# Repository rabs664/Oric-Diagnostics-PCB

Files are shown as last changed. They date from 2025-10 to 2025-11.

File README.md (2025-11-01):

# Oric Diagnostics PCB
This is a reproduction of Mike Brown's Oric Diagnostic board and loopback harnesses, see [Mike Brown's Diagnostic ROM and PCB](https://oric.signal11.org.uk/html/diagrom.htm)

>[!NOTE]
>Acknowledgements go to Mike Brown for posting the original design to his excellent website [Oric And Atmos Support](https://oric.signal11.org.uk/index.htm). Many Thanks.



>[!CAUTION]
>USE AT YOUR OWN RISK.
>There is always the risk that the Oric Diagnostic board could cause harm to your Oric. Although I have tested the Oric Diagnostic board, there is no guarantee that it
>will work properly under all circumstances.

# Repository Content
This repository contains the KiCad and gerber files associated with the Diagnostic board and loopback harnesses.

# Changes from Mike Brown's Original Design
The following changes have been made from Mike Brown's Original Design:

* The clock circuit has been replaced by an [ECS-100AX-010](https://www.digikey.co.uk/en/products/detail/ecs-inc/ECS-100AX-010/827230) oscillator.

* The LED resistors have been replaced with 220ohm values.
>[!TIP]
>I still found the LEDs quite bright and you may consider increasing this value.

* LS components replaced with HCT.

* 3M holes have been added to allow for standoffs to be fitted.

For all other information about Mike Brown's original design please refer to [Mike Brown's website](https://oric.signal11.org.uk/html/diagrom.htm)

# Ribbon Cable
The Oric Diagnostic board has been designed to be used with a 34-way ribbon cable and can be used partly when the Oric motherboard is still in the case, altough it is a bit difficult to use the NMI button underneath.



However for the most part it will probably be used when the Oric motherboard has been removed from the case, but remember the motherboard is normally upside down and hence the twist in the ribbon cable when used in this configuration.



>[!TIP]
>Note the orientation of the ribbon connectors and red cable aligned to pin 1 and check connectivity back to the Oric motherboard before use.



# Port A Loopback
The Port A loopback is designed to fit straight into the Oric printer port.



>[!TIP]
>I found it difficult to remove the Port A Loopback when required. In the end I placed a pin header on the wrong side of the PCB and connected using a ribbon cable.
>
> 

# Keyboard Loopback
The Keyboard loopback is designed to fit over the end 10 pins.



>[!NOTE]
>I struggled to find pin headers that fitted. In the end I used these [pin headers](https://www.digikey.co.uk/en/products/detail/samtec-inc/SSA-110-S-T/1105806) but they are not a perfect fit.

# Casette Loopback
The Casette loopback is not part of this repository please refer to [Mike Brown's Diagnostic ROM and PCB page](https://oric.signal11.org.uk/html/diagrom.htm)

# 1MHz Clock
>[!NOTE]
>I have not had a need to use the clock source yet.



# ROM
Please refer to [Mike Brown's Diagnostic ROM and PCB page](https://oric.signal11.org.uk/html/diagrom.htm)

>[!NOTE]
>I used a 27C512 EPROM and copied the 16K ROM image four times to fill the 64K EPROM.

# Jumpers
Please refer to [Mike Brown's Diagnostic ROM and PCB page](https://oric.signal11.org.uk/html/diagrom.htm)

>[!CAUTION]
>I have not tested the jumpers A14=0, A15=0, INHIBIT VIA and VIA SEL

# Testing
The Oric Diagnostic board has been tested on two Oric-1 computers. One Oric-1 passed all tests and the other failed on the Casette Input test (which was resolved by replacing the LM358 OpAmp). So unfortunately I have not yet had to use the Oric Diagnostic board extensively on a fully failed computer.



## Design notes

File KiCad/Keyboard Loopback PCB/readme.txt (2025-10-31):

This folder contains the KiCad Project and gerbers for the Keyboard Loopback PCB.

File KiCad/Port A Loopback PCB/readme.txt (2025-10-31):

This folder contains the KiCad Project and gerbers for the Port A Loopback PCB.

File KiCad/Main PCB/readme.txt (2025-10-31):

This folder contains the KiCad Project and gerbers for the main Oric Diganostic PCB.

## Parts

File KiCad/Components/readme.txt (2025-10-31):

This folder contains the footprints for some components used in the KiCad project.

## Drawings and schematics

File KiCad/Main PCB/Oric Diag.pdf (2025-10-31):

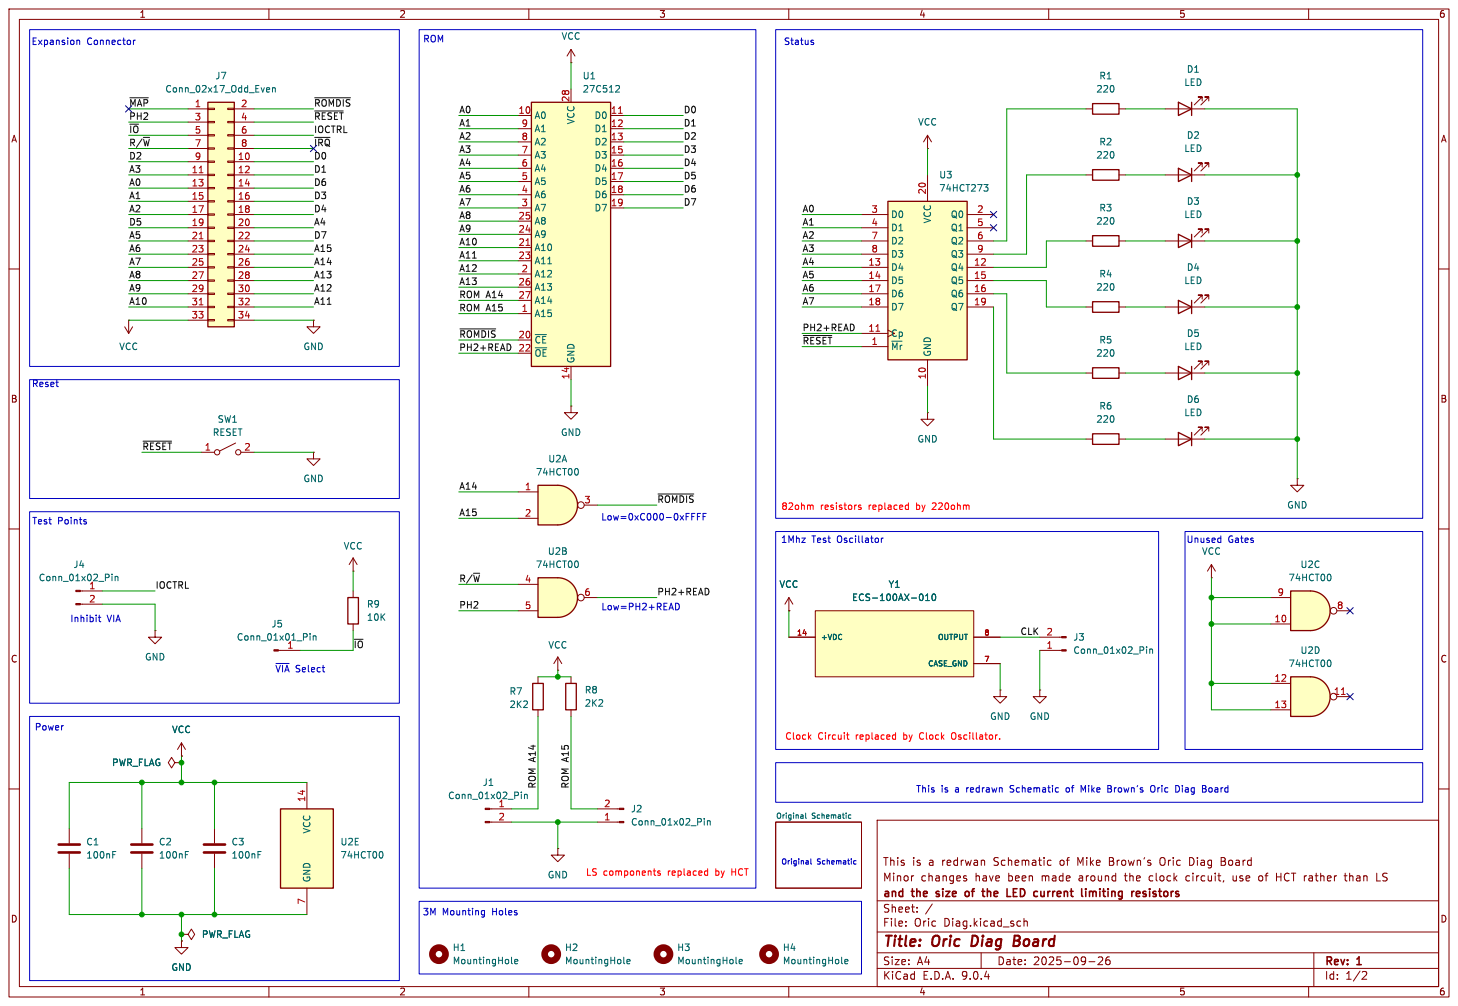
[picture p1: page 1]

Id: 1/2 Title: Oric Diag Board

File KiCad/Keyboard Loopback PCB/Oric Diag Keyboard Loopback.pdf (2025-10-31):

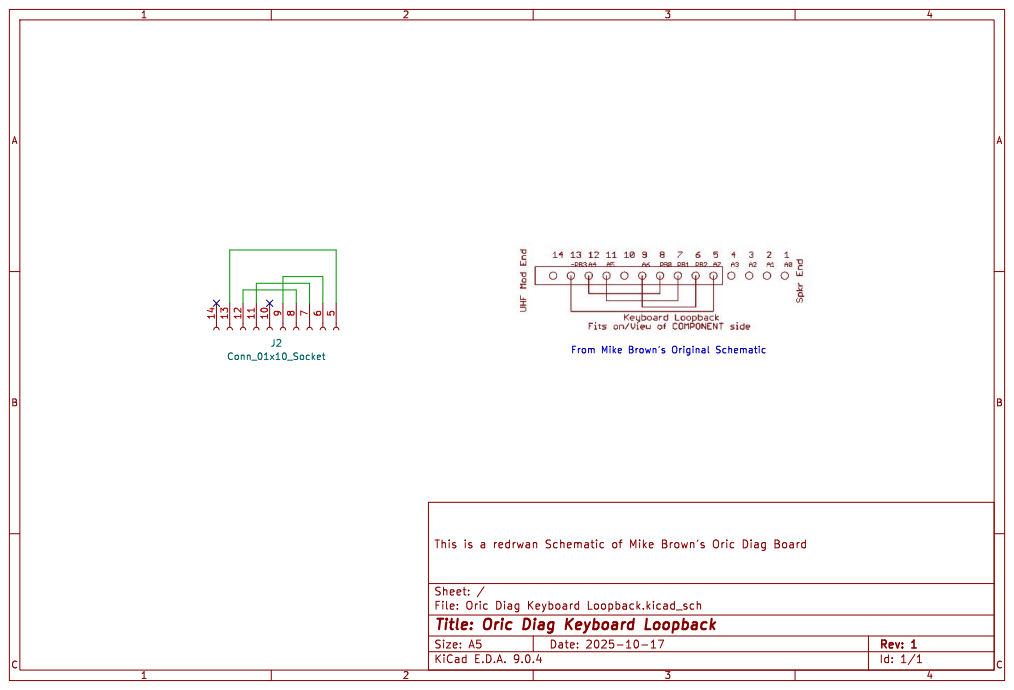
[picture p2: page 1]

51413121110 J2 Conn_01x10_Socket From Mike Brown's Original Schematic

Id: 1/1 Title: Oric Diag Keyboard Loopback

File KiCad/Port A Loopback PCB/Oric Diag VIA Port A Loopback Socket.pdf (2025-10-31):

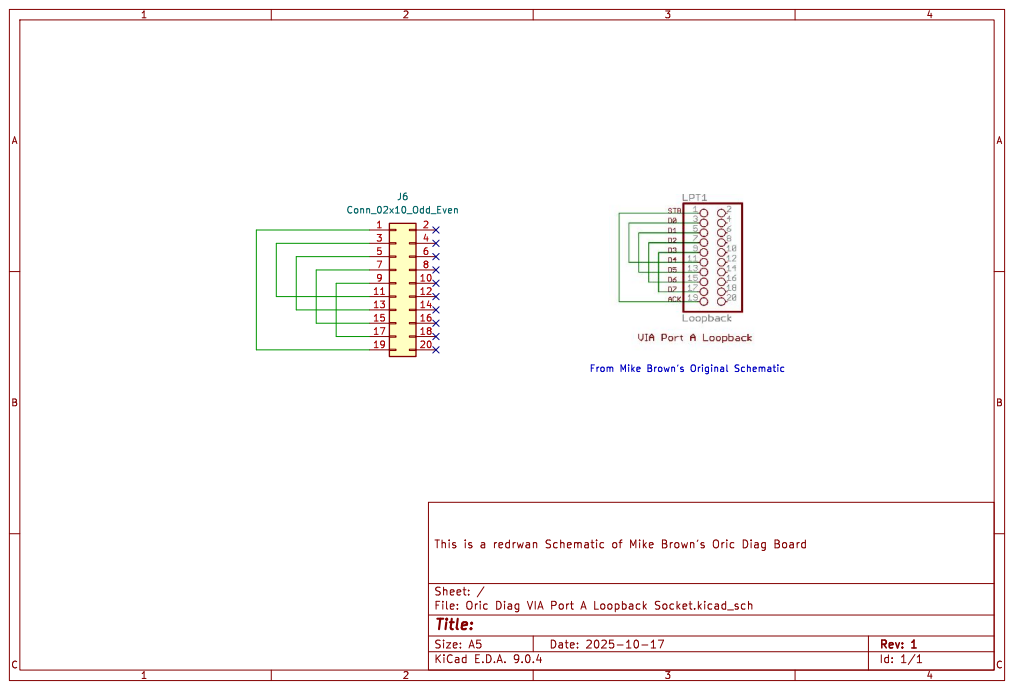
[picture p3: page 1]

9 | 10
11 | 12
13 | 14
15 | 16
17 | 18

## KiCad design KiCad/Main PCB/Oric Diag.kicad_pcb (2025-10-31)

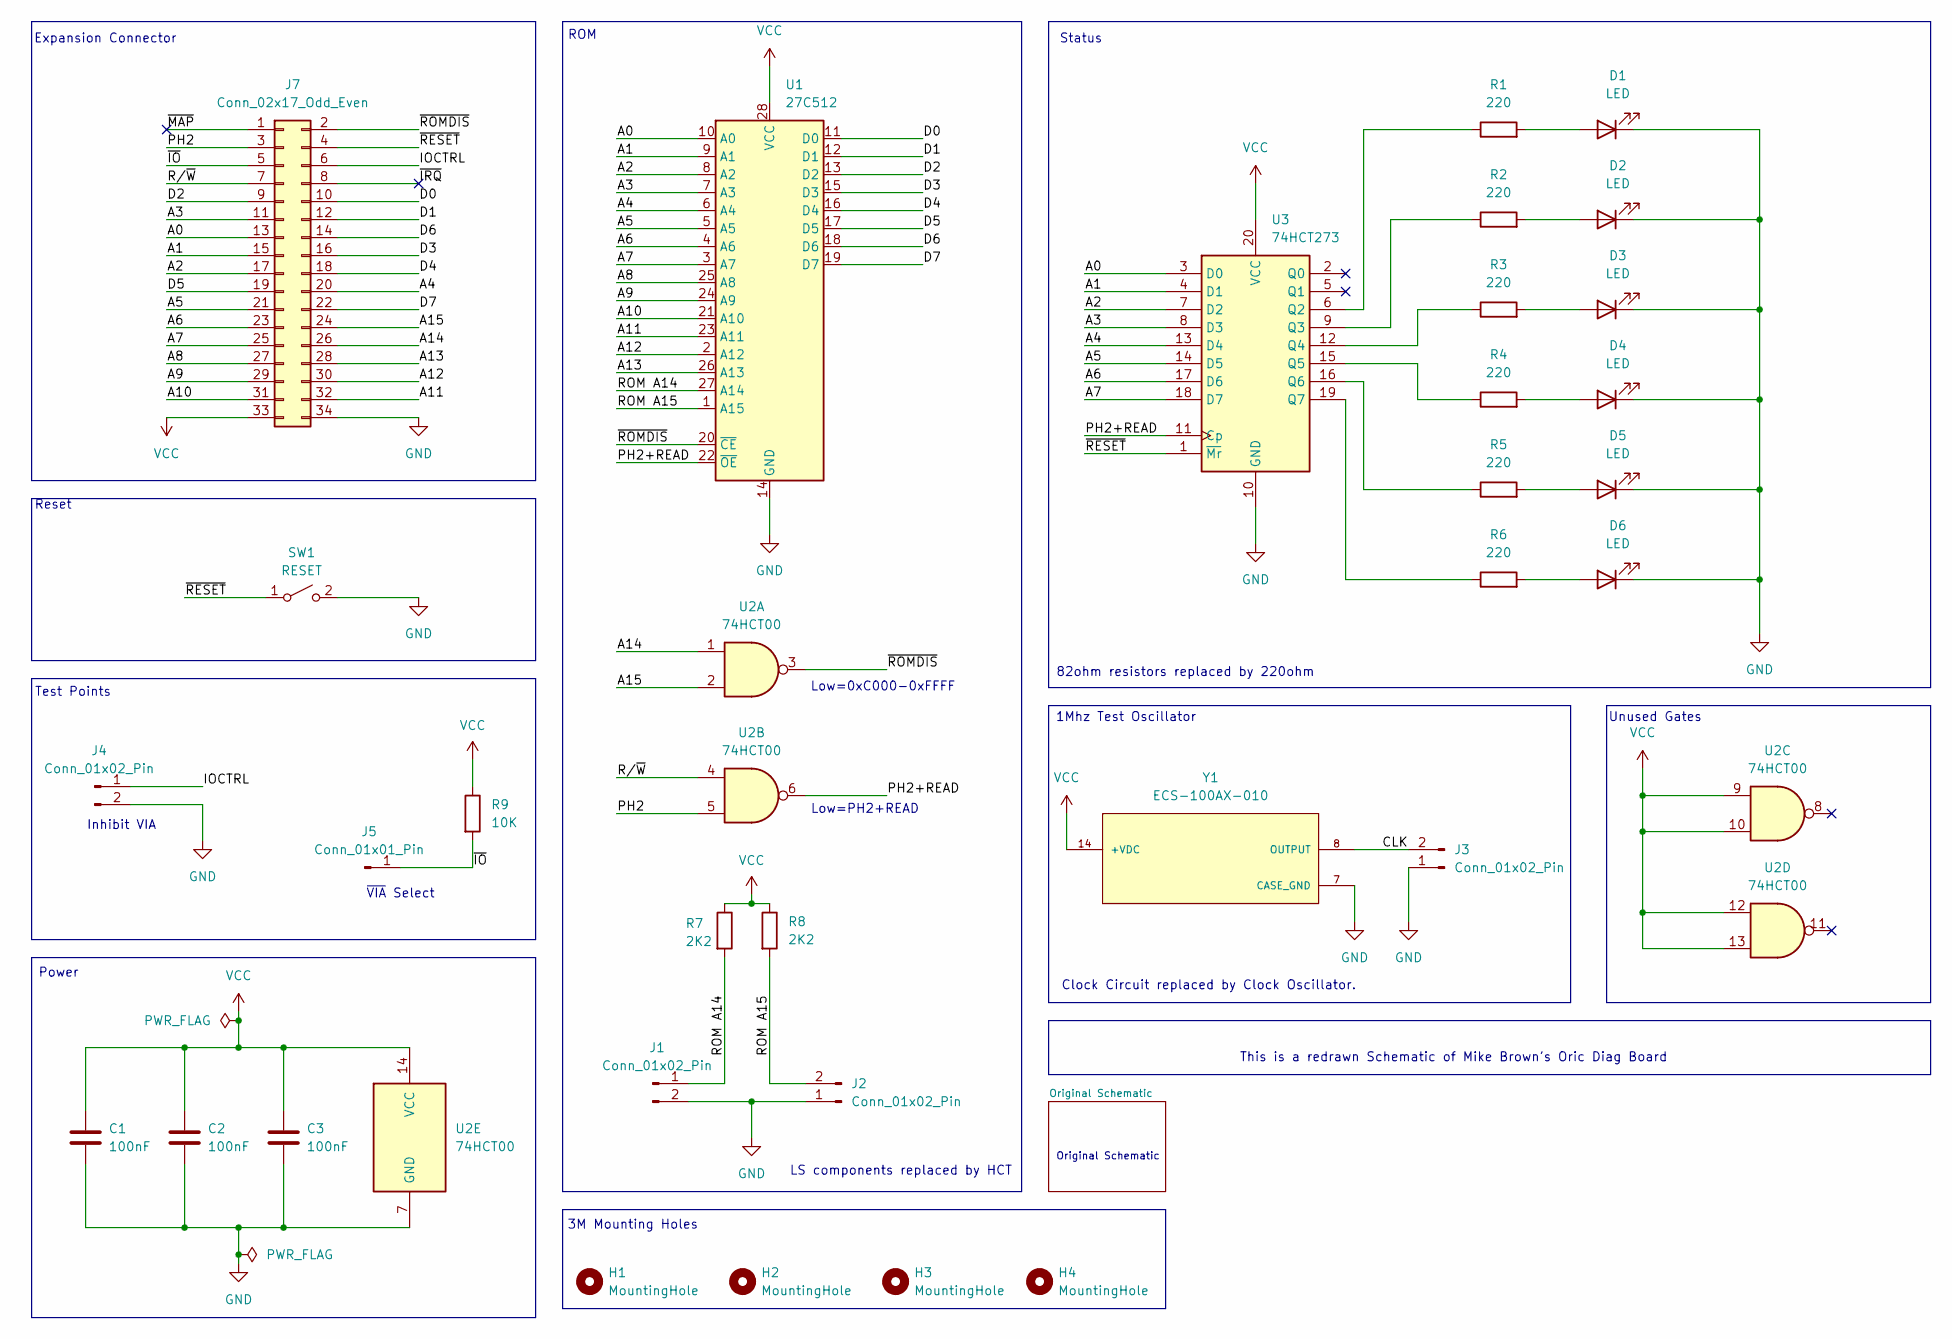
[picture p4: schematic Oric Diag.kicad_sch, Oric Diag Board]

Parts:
C1, C2, C3: 100nF; C_Disc_D5.0mm_W2.5mm_P5.00mm
D1, D2, D3, D4, D5, D6: LED; LED_D3.0mm
H1, H2, H3, H4: MountingHole; MountingHole_3.2mm_M3
J1, J2, J3, J4: Conn_01x02_Pin; PinHeader_1x02_P2.54mm_Vertical
J5: Conn_01x01_Pin; PinHeader_1x01_P2.00mm_Vertical
J7: Conn_02x17_Odd_Even; IDC-Header_2x17_P2.54mm_Vertical
R1, R2, R3, R4, R5, R6: 220; R_Axial_DIN0207_L6.3mm_D2.5mm_P7.62mm_Horizontal
R7, R8: 2K2; R_Axial_DIN0207_L6.3mm_D2.5mm_P7.62mm_Horizontal
R9: 10K; R_Axial_DIN0207_L6.3mm_D2.5mm_P7.62mm_Horizontal
SW1: RESET; SW_PUSH_6mm_H9.5mm
U1: 27C512; DIP-28_W15.24mm
U2: 74HCT00; DIP-14_W7.62mm_Socket
U3: 74HCT273; DIP-20_W7.62mm
Y1: ECS-100AX-010; OSC_ECS-100AX-010

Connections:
/A0: J7.13, U1.10 (A0), U3.3 (D0)
/A1: J7.15, U1.9 (A1), U3.4 (D1)
/A2: J7.17, U1.8 (A2), U3.7 (D2)
/A3: J7.11, U1.7 (A3), U3.8 (D3)
/A4: J7.20, U1.6 (A4), U3.13 (D4)
/A5: J7.21, U1.5 (A5), U3.14 (D5)
/A6: J7.23, U1.4 (A6), U3.17 (D6)
/A7: J7.25, U1.3 (A7), U3.18 (D7)
/A8: J7.27, U1.25 (A8)
/A9: J7.29, U1.24 (A9)
/A10: J7.31, U1.21 (A10)
/A11: J7.32, U1.23 (A11)
/A12: J7.30, U1.2 (A12)
/A13: J7.28, U1.26 (A13)
/A14: J7.26, U2.1
/A15: J7.24, U2.2
/CLK: J3.2, Y1.8 (OUTPUT)
/D0: J7.10, U1.11 (D0)
/D1: J7.12, U1.12 (D1)
/D2: J7.9, U1.13 (D2)
/D3: J7.16, U1.15 (D3)
/D4: J7.18, U1.16 (D4)
/D5: J7.19, U1.17 (D5)
/D6: J7.14, U1.18 (D6)
/D7: J7.22, U1.19 (D7)
/IOCTRL: J4.1, J7.6
/PH2: J7.3, U2.5
/PH2+READ: U1.22 (~OE), U2.6, U3.11 (Cp)
/ROM A14: J1.1, R7.2, U1.27 (A14)
/ROM A15: J2.2, R8.2, U1.1 (A15)
/R/~W: J7.7, U2.4
/~IO: J5.1, J7.5, R9.2
/~IRQ: J7.8
/~MAP: J7.1
/~RESET: J7.4, SW1.1 (A), U3.1 (~Mr)
/~ROMDIS: J7.2, U1.20 (~CE), U2.3
GND: C1.2, C2.2, C3.2, D1.1 (K), D2.1 (K), D3.1 (K), D4.1 (K), D5.1 (K), D6.1 (K), J1.2, J2.1, J3.1, J4.2, J7.34, SW1.2 (B), U1.14 (GND), U2.7 (GND), U3.10 (GND), Y1.7 (CASE_GND)
unnamed: D1.2 (A), R1.2
unnamed: D2.2 (A), R2.2
unnamed: D3.2 (A), R3.2
unnamed: D4.2 (A), R4.2
unnamed: D5.2 (A), R5.2
unnamed: D6.2 (A), R6.2
unnamed: R1.1, U3.6 (Q2)
unnamed: R2.1, U3.9 (Q3)
unnamed: R3.1, U3.12 (Q4)
unnamed: R4.1, U3.15 (Q5)
unnamed: R5.1, U3.16 (Q6)
unnamed: R6.1, U3.19 (Q7)
VCC: C1.1, C2.1, C3.1, J7.33, R7.1, R8.1, R9.1, U1.28 (VCC), U2.9, U2.10, U2.12, U2.13, U2.14 (VCC), U3.20 (VCC), Y1.14 (+VDC)

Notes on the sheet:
1Mhz Test Oscillator
Power
Clock Circuit replaced by Clock Oscillator.
ROM
Low=0xC000-0xFFFF
Test Points
3M Mounting Holes
Reset
Unused Gates
Inhibit VIA
This is a redrawn Schematic of Mike Brown's Oric Diag Board
Original Schematic
LS components replaced by HCT
Expansion Connector
Low=PH2+READ
~{VIA} Select
82ohm resistors replaced by 220ohm
Status

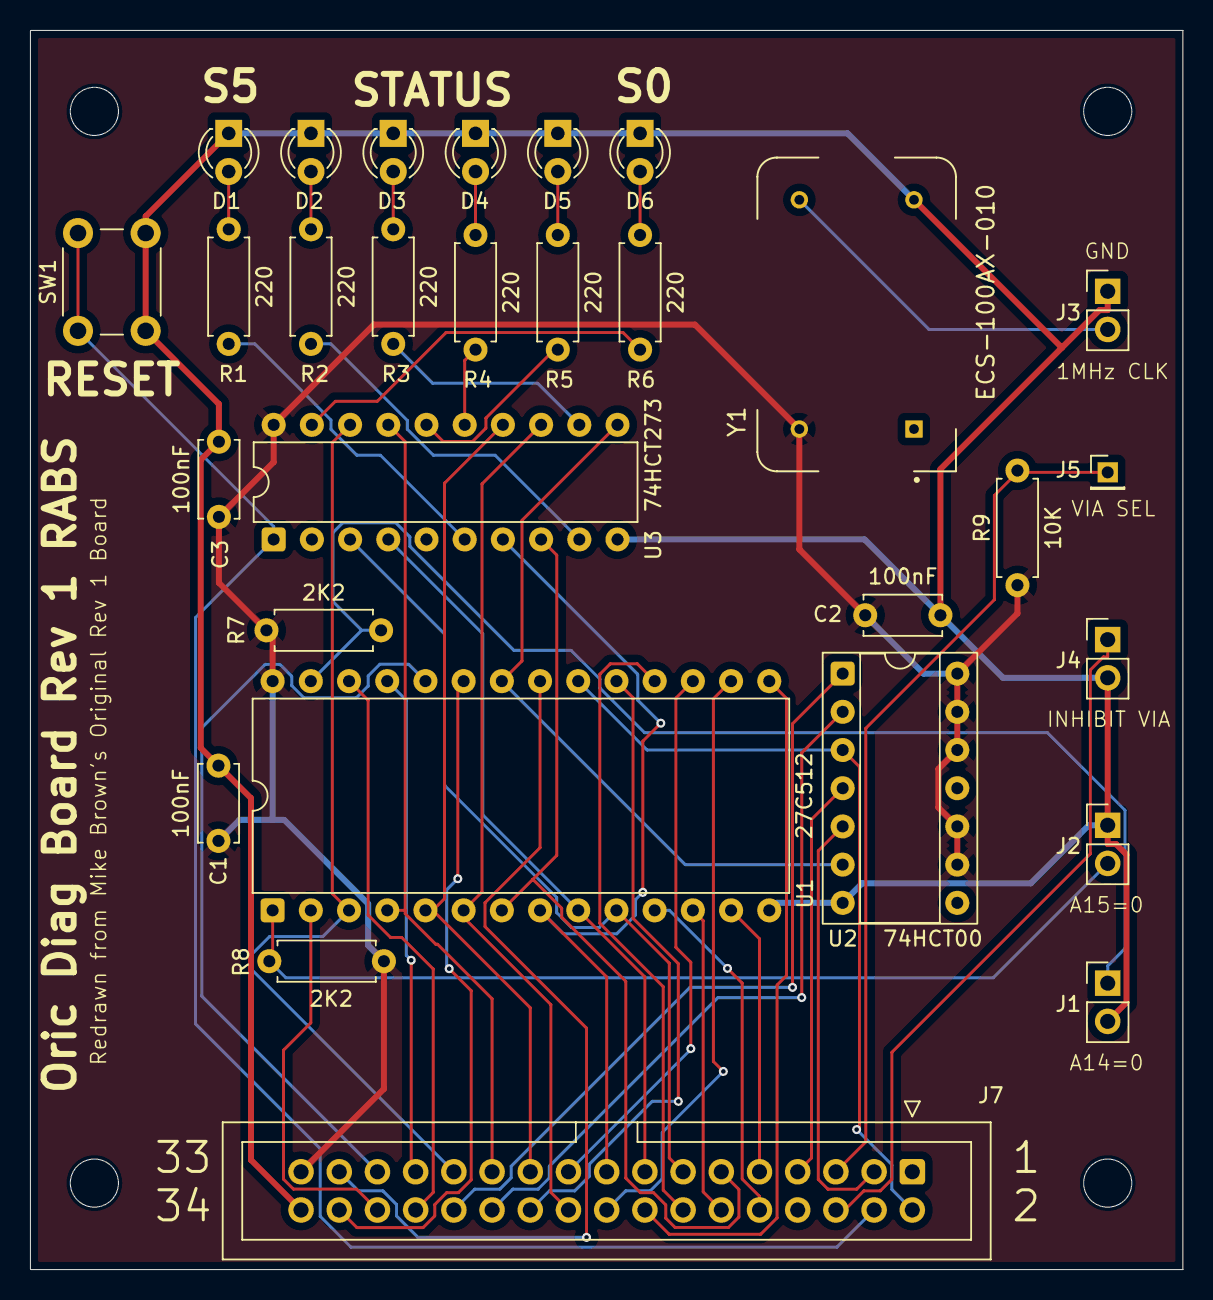
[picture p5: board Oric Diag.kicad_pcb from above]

Board: 2 copper layers, 76.6 x 82.4 mm, 33 parts (0 on the bottom side), 48 nets.

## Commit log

2025-10-31 Update README with ribbon cable usage details
    Added information about the ribbon cable usage with the Oric Diagnostic board, including orientation and configuration notes.
2025-10-31 Add readme for main Oric Diagnostic PCB
2025-10-31 Create readme for Port A Loopback PCB
    Added readme file for Port A Loopback PCB project.
2025-10-31 Add readme for Keyboard Loopback PCB project
2025-10-31 Create readme.txt for components directory
    Add readme file for components folder in KiCad project
